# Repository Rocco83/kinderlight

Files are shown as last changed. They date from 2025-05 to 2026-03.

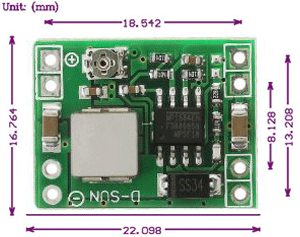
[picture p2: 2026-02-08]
docs/MP1584-Dimensions.png

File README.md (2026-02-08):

# KinderLight RGB

KinderLight RGB is a smart night light based on an ESP32-C6 microcontroller,
capable of automatically adjusting brightness and color based on ambient light using a BH1750 sensor.

Designed to integrate natively with **Home Assistant** via **ESPHome**.

---

## Features

- Automatic ambient light detection with BH1750 sensor.
- RGB LED control via PWM (independent channels for Red, Green, Blue).
- Wi-Fi control and OTA (Over The Air) firmware updates.
- Web server interface for local diagnostics.
- Optional manual serial debug connection via JST-SH 5P or Tag-Connect footprint (future).
- Easy snap-in mount inside a **Vimar Plana** 14041 cover plate.
- Input voltage 7–24V regulated to 5V with buck converter.
- Smooth fade-in and fade-out effects.
- Automatic activation from sunset to sunrise (future).

## Hardware Required

- ESP32-C6 Supermini
- BH1750 light sensor module
- MP1584 DC-DC Stepdown Module
- RGB LED (common anode)
- 3D printed snap-in panel for Vimar 14041
- optionally, the PCB to host the components, otherwise replicate the same BOM

## Software

- ESPHome (latest)
- Home Assistant (latest)
- YAML automations provided.

## Installation

1. Flash the ESP32 using provided `kinderlight.yaml` ESPHome config.
2. Install the snap-in panel inside a Vimar 14041 (or custom box).
3. Wire the RGB LED and the BH1750 sensor
4. Upload automations to Home Assistant.

## Configuration

Lux table:
0.0 - 2.0 lx: Danger Zone (High risk of tripping/hitting furniture).
2.0 - 5.0 lx: Deep Twilight (Silhouettes only; no colors or textures visible).
5.0 - 10.0 lx: Twilight (General shapes visible; fine details are lost).
10.0 - 15.0 lx: Low Orientation (Safe to move; colors begin to be distinguishable).
15.0 - 20.0 lx: Dim Orientation (Comfortable for a nightlight; eye starts to adapt).
20.0 - 30.0 lx: Gloomy Interior (Environment feels "dark" but fully visible).

## Entities Created

- `light.kinderlight_rgb`
- `sensor.ambient_light_lux`

(Optional Voltage monitor if configured.)

## Automation Logic

- Turns on at sunset, off at sunrise.
- During daytime, activates if ambient lux falls below threshold.
- Full color control from Home Assistant dashboard.

## Future Plans

- Support for multiple KinderLights via groups.
- Additional effects (color cycling, breathing mode).

## License

GPL-3.0 License

---

## Project Structure

```plaintext
kinderlight_rgb/
├── README.md
├── LICENSE
├── hardware/
│   └── 3d_models/
│       ├── snapin_14041.stl
│       └── 
├── firmware/
│   ├── kinderlight_rgb.yaml
│   ├── example_automation.yaml
├── bom/
│   ├── bom_front.csv
│   ├── bom_rear.csv
└── tools/
    ├── wiring_diagram.svg
    └── wiring_diagram.png

## Backlog

MP1584 dimensions for kicad has been taken from:

https://components101.com/modules/mini-mp1584-dc-dc-3a-adjustable-buck-module

[docs/MP1584-Dimensions.png]
[docs/MP1584-Pinout.jpg]

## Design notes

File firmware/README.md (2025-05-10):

# KinderLight Firmware

This directory contains the ESPHome configuration for the KinderLight RGB nightlight device.

## 📦 Files

- `kinderlight.yaml`: main ESPHome configuration file for the ESP32 controller.
- `secrets.yaml.example`: example of the secrets file you need to set up for WiFi credentials.

## 🔧 Hardware Configuration

| Component | GPIO  | Notes |
|---|---|---|
| RGB LED - Red PWM | GPIO14 | Controlled via IRLML6344 MOSFET |
| RGB LED - Green PWM | GPIO27 | " |
| RGB LED - Blue PWM  | GPIO26 | " |
| I2C SDA | GPIO21 | Used for BH1750 light sensor |
| I2C SCL | GPIO22 | " |

## 💡 Functionality

- **RGB LED light** with full Home Assistant control.
- **Smooth fading** transitions.
- **BH1750 ambient light sensor** for automatic on/off logic.
- Optional **voltage/battery monitoring** (coming soon).

## 🚀 Flash Instructions

1. Copy `kinderlight.yaml` into your ESPHome config folder.
2. Duplicate `secrets.yaml.example` into your root ESPHome directory as `secrets.yaml`, and set your WiFi credentials.
3. Flash via USB or OTA:
   ```bash
   esphome run kinderlight.yaml

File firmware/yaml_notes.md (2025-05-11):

# KinderLight RGB - YAML Notes

## 📋 General Information

- Firmware is compatible with ESPHome 2024.x versions.
- Ambient light detection using BH1750 sensor over I2C bus.
- RGB LED controlled through independent PWM channels.

## 🛠️ GPIO Pin Assignments

| Function | GPIO |
|---|---|
| PWM Red (LED) | GPIO1 |
| PWM Green (LED) | GPIO2 |
| PWM Blue (LED)  | GPIO3 |
| SDA (I2C Data)  | GPIO8 |
| SCL (I2C Clock) | GPIO9 |

> **Note**:  
> These pin assignments can be modified if needed in the `kinderlight_rgb.yaml` file.

## 🔥 Key Recommendations

- Use **IRLML6344** SOT-23 MOSFETs for production PCB (small, efficient).
- For breadboard testing, you can use **2N7000** MOSFETs (TO-92 package) **without any circuit changes**.
- Recommended PWM frequency: **at least 1000Hz** to avoid visible flicker.

## ⚙️ Electrical Characteristics

- Input voltage range: **10V–12V DC**.
- Buck converter module MP1584EN reduces voltage to stable 5V.
- Ambient light detection threshold: adjustable via YAML, default is **<50 lux** to consider it dark.

## 🛜 Network & OTA

- OTA updates are enabled.
- A fallback Access Point will be created if Wi-Fi is not available during boot.
- Web server interface available at device's IP address (port 80).

---

# 📦 Important Notes

- ESP32-C3 board must be properly connected to the rear PCB via a 5P JST-SH connector.
- Ambient light sensor BH1750 uses I2C address `0x23`.
- RGB light can be fully controlled from Home Assistant dashboards.
- Automation examples are available under `example_automation.yaml`.

---

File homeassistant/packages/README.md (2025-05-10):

         +----------------+
         |    Home Assistant|
         +----------------+
                  |
                  v
         +----------------+
         | sun.sun changes |
         +----------------+
             /        \
            /          \
         sunset       sunrise
           |             |
           v             v
   light.turn_on   light.turn_off
 (with fade 2s)    (with fade 2s)

                  |
                  v
         +----------------+
         | Ambient Light   |
         | Sensor (lux)    |
         +----------------+
             /        \
            /          \
        lux < 30     lux > 50
           |             |
           v             v
   light.turn_on   light.turn_off
 (only daytime)   (only daytime)

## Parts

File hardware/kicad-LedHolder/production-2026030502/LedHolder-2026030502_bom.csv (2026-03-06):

Designator | Footprint | Quantity | Value | LCSC Part #
J1 | JST_PH_S4B-PH-SM4-TB_1x04-1MP_P2.00mm_Horizontal | 1 | JST | C265102
LED1 | LED_D5.0mm-4_RGB_nopackage | 1 | LED_5mm_RABG

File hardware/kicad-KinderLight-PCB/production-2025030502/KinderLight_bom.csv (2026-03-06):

Designator | Footprint | Quantity | Value | LCSC Part #
J1 | PinSocket_1x02_P2.54mm_Vertical | 1 | +5VCC
J10 | JST_PH_B4B-PH-K_1x04_P2.00mm_Vertical | 1 | LED PWM JST | C131334
J11 | JST_PH_B4B-PH-K_1x04_P2.00mm_Vertical | 1 | I2C BH1750 JST | C131334
J2, J6 | PinSocket_1x02_P2.54mm_Vertical | 2 | GND
J3 | PinSocket_1x10_P2.54mm_Vertical | 1 | ESP32C6 Left
J4 | PinSocket_1x10_P2.54mm_Vertical | 1 | ESP32C6 Right
J5 | PinSocket_1x02_P2.54mm_Vertical | 1 | VCC
J7 | JST_XH_B4B-XH-AM_1x04_P2.50mm_Vertical | 1 | I2C BH1750 XH | C161871
J8 | JST_XH_B4B-XH-AM_1x04_P2.50mm_Vertical | 1 | LED PWM | C161871
J9 | TerminalBlock_Phoenix_MKDS-1,5-2-5.08_1x02_P5.08mm_Horizontal | 1 | +12VCC | C22397914
Q1, Q2, Q3 | SOT-23 | 3 | AO3400A | C20917
R1, R2, R3 | 0805 | 3 | 220R | C17557
R4, R5, R6 | 0805 | 3 | 150R | C17471

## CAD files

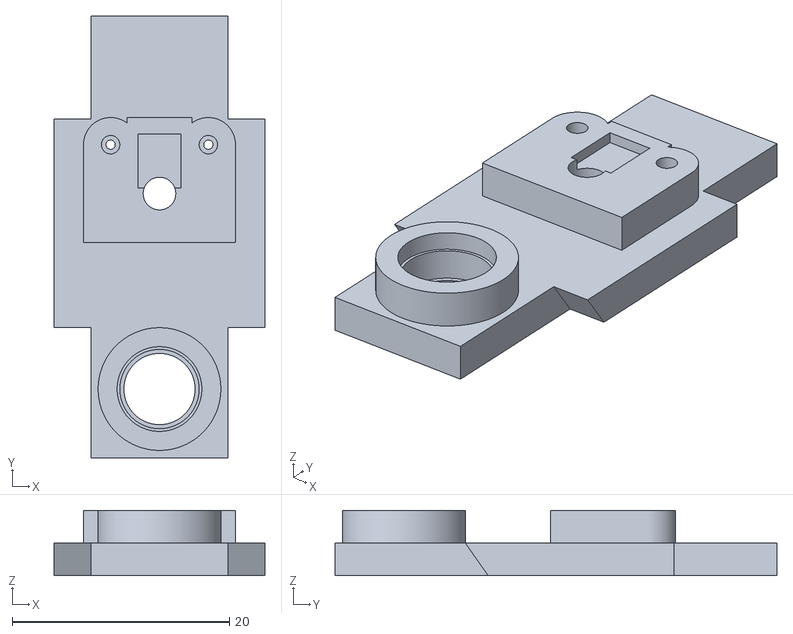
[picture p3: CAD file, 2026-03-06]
hardware/3d_models/snapin_14041_20260130.stl
19.4 x 40.7 x 6.00

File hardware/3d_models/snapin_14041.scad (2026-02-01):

// KinderLight RGB - Snap-in for Vimar 14041 with BH1750 Tower, M2 Towers, and True Snap Hooks
// License: GPL-3.0

//$fn = 20;  // rendering test
$fn = 200; // Smooth curves

// -----------------------------------------------------------------------------
// Main parameters
// -----------------------------------------------------------------------------
// WARNING: PLANA 14041 changed over the time. ensure to have "new" modules

width     = 19.40; // calibro 19,26 (loose) 19,51 (forcing the plastic) - lato non deve premere.
// con 19.26 reali ha ancora agio ma sta bloccato bene
// con 19.27 stampa 19.15
height    = 40.70; // calibro 40,54 (loose) 40,78 (forcing the plastic)
// con 40.58 reali ha ancora agio ma sta bloccato bene
// con 40.58 stampa 40.43
thickness = 3;

abbondanza = 4;

// -----------------------------------------------------------------------------
// Cut of the upper and lower part
// -----------------------------------------------------------------------------
central_module_width = 12.60; // calibro 12.36 in fondo. 12.42 reali ha ancora agio
// con 12.47 reali ha ancora agio ma sta bloccato bene
// con 12.50 stampa 12.39

// 19.3-(3.4*2)=12.5 al contrario: (19.3-central_module_width)/2
slot_depth  = (width - central_module_width) / 2; // "x" (quanto entra verso il centro)
slot_length = 9.5;                                // "y" (lunghezza del taglio lungo il bordo)

// -----------------------------------------------------------------------------
// LED and Sensor positions
// -----------------------------------------------------------------------------
led_pos_y = -14;
led_walls_tickness = 2;
// led diameter: 5mm (si incastra bene)
// led back diameter (che non esce): 5,5mm

hole_diameter_led_pass = 6.55; // Foro dove passa la testa del porta LED
hole_diameter_led_seat = 7.30; // Foro per la base/corpo del porta LED +0.2mm
hole_diameter_led_remove = hole_diameter_led_seat+0.5; // Foro dove passa la testa del porta LED
flange_thickness       = 2;    // Spessore della flangia per NON fare passare il led + 1mm
flange_top_led_remove  = 1.5;
gommino_clearance      = 0;    // 14041 have exactly 2mm spessore

// Sensor hole
sensor_pos_y = 4; // measured, posizione del *sensore* rispetto ad y=0

// -----------------------------------------------------------------------------
// BH1750 main tower
// -----------------------------------------------------------------------------
tower_height           = 3; // 1mm si intravede il foro. 2mm/3mm OK
tower_outer_diameter   = 9; // diametro massimo altrimenti tocca gli altri componenti
tower_inner_diameter   = 7; // which is also sensor diameter

// -----------------------------------------------------------------------------
// Mini-towers M2 screws
// -----------------------------------------------------------------------------
m2_tower_outer_diameter = 5;
m2_tower_inner_diameter = 1.7; // 2.0mm filetto esterno, 1.7mm filetto interno
m2_tower_offset_x       = 4.5;
m2_tower_offset_y       = sensor_pos_y + 4.5; // verificato con calibro


// -----------------------------------------------------------------------------
// MODULES
// -----------------------------------------------------------------------------

// Snap-in base
module snapin_plate() {
    difference() {
        union() {
            // piastra base
            cube([width, height, thickness], center = true);
            // cubo di rinforzo
            translate([0, sensor_pos_y, thickness / 2])
                cube([14, tower_outer_diameter, tower_height * 2], center = true);
            // cilindro per non far fare troppa luminosita' al led
            translate([0, led_pos_y, thickness / 2])
                // il cilindro è alto come la torre per sicurezza
                cylinder(h = tower_height, d = hole_diameter_led_seat+(led_walls_tickness*2));
        }

        // --- SISTEMA FORO LED CON FLANGIA ---
        // 1. Foro passante centrale
        translate([0, led_pos_y, 0])
            cylinder(h = thickness + abbondanza, d = hole_diameter_led_pass, center = true);

        // 2. Scasso per il corpo del LED
        // la flangia deve avere 2 diametri per permettere l'inserimento del led
        translate([0, led_pos_y, -thickness / 2 + flange_thickness])
            cylinder(h = thickness + abbondanza, d = hole_diameter_led_seat);
        // la parte in alto deve avere un minimo di scasso per permettere l'inserimento e l'estrazione del led
        translate([0, led_pos_y, (thickness / 2) + tower_height - flange_top_led_remove])
            cylinder(h = thickness + abbondanza, d = hole_diameter_led_remove);


        // Sensor hole
        scasso_cavi_sensore();

        // Right+left hole for the screw
        buco_per_viti();

        // --- PARAMETRI EXTRA PER GLI SCASSI ---
        slot_extension_length = 2.5; // Lunghezza erosione rettangolare
        cutout_angle          = 35;  // Angolo dello scasso

        // Four vertical notches on long sides
        for (side = [-1, 1]) { // sinistra/destra
            x_pos = side * (width / 2 - slot_depth / 2);

            for (edge = [-1, 1]) { // sopra/sotto
                // Posizionamento Y base
                y_pos = edge * (height / 2 - slot_length / 2);

                // 1. Scasso originale standard
                translate([x_pos, y_pos, 0])
                    cube([slot_depth, slot_length, thickness + abbondanza], center = true);

                // --- MODIFICA SU RICHIESTA (edge -1) ---
                if (edge == -1) {
                    
                    // Direzione verso il centro (per Y neg è 1)
                    dir_to_center = 1;

                    // Bordo interno dello scasso originale
                    y_inner_edge = y_pos + dir_to_center * (slot_length / 2);

                    // 1) ERODI LUNGHEZZA PARAMETRICA
                    translate([x_pos, y_inner_edge + dir_to_center * (slot_extension_length / 2), 0])
                        cube([slot_depth, slot_extension_length, thickness + abbondanza], center = true);

                    // 2) SCAVO TRIANGOLARE PARAMETRICO
                    y_prism_start = y_inner_edge + dir_to_center * slot_extension_length;

                    // Calcolo dello sbalzo (cateto orizzontale) basato sull'angolo
                    offset_y = thickness * tan(cutout_angle);

                    translate([x_pos, y_prism_start, 0])
                        rotate([90, 0, 90])
                        linear_extrude(height = slot_depth, center = true)
                        polygon(points = [
                            // Largo sotto, stretto sopra
                            [0, thickness / 2], // In ALTO: Punta stretta
                            [0, -thickness / 2], // In BASSO: Inizio base larga
                            // In BASSO: Fine base larga calcolata trigonometricamente
                            [dir_to_center * offset_y, -thickness / 2]
                        ]);
                }
            }
        }
    }
}

module scasso_cavi_sensore() {
    // Posizionamento sulla cima della torre tra M2 e Sensore
    translate([0, m2_tower_offset_y, (thickness / 2 + tower_height)])
        translate([-2, -4, -0.9])
        cube([4, 5, 0.91]);

    vimar_tickness          = 1.9;
    base_cone               = 2;
    top_cone                = 2;
    sensor_minimum_diameter = 3;

    z0cone                     = -thickness / 2 - vimar_tickness;
    cone_groove_width          = 2;   // la parte del gommino che deve passare
    cone_groove_inner_diameter = 7.5; // gommino 7.00, tieni del margine 
    cone_groove_outer_diameter = 9;   // parte esterna gommino
    cone_top_width             = 3.5;   // altezza dopo groove fino a top

    // #1 2mm dritto dalla base (base_cone)
    translate([0, sensor_pos_y, z0cone])
        cylinder(h = base_cone, d = tower_inner_diameter);

    // #2 cono
    translate([0, sensor_pos_y, z0cone + base_cone])
        cylinder(h = thickness + tower_height - top_cone,
            d1 = tower_inner_diameter,
            d2 = 3); // sensor longest side: 2.5mm. 3 for clearance

    // #3 2mm dritto (top_cone)
    translate([0, sensor_pos_y, z0cone + base_cone + thickness + tower_height - top_cone])
        cylinder(h = top_cone, d = sensor_minimum_diameter);


    // OPZIONALE, spazio per il gommino
    spazio_per_gommino = 1;
    if (spazio_per_gommino == 1) {
        // dalla base, altezza della base, fai scasso con diametro esterno
        translate([0, sensor_pos_y, z0cone])
            cylinder(h = cone_groove_width, d = cone_groove_inner_diameter);

        // spazio per incastro parte alta gommino        
        translate([0, sensor_pos_y, z0cone + cone_groove_width])
            cylinder(h = cone_top_width, d1 = cone_groove_outer_diameter, d2 = cone_groove_inner_diameter);
    }
}
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

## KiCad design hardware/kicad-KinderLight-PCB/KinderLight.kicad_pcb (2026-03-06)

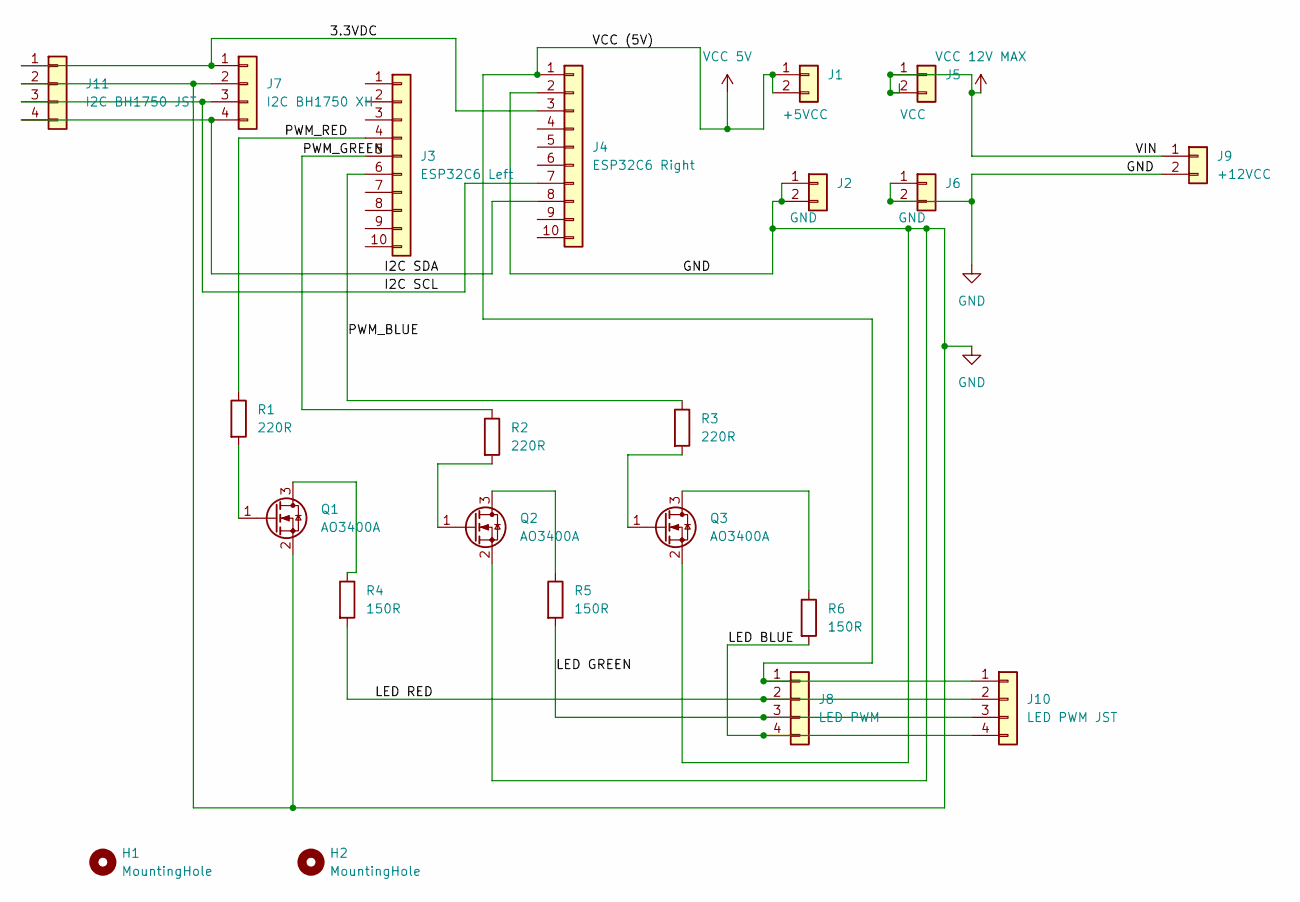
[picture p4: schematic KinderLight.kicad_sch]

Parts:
H1, H2: MountingHole; MountingHole_3.2mm_M3
J1: +5VCC; PinSocket_1x02_P2.54mm_Vertical
J2, J6: GND; PinSocket_1x02_P2.54mm_Vertical
J3: ESP32C6 Left; PinSocket_1x10_P2.54mm_Vertical
J4: ESP32C6 Right; PinSocket_1x10_P2.54mm_Vertical
J5: VCC; PinSocket_1x02_P2.54mm_Vertical
J7: I2C BH1750 XH; JST_XH_B4B-XH-AM_1x04_P2.50mm_Vertical; LCSC C161871
J8: LED PWM; JST_XH_B4B-XH-AM_1x04_P2.50mm_Vertical; LCSC C161871
J9: +12VCC; TerminalBlock_Phoenix_MKDS-1,5-2-5.08_1x02_P5.08mm_Horizont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; LCSC C22397914
J10: LED PWM JST; JST_PH_B4B-PH-K_1x04_P2.00mm_Vertical; LCSC C131334
J11: I2C BH1750 JST; JST_PH_B4B-PH-K_1x04_P2.00mm_Vertical; LCSC C131334
Q1, Q2, Q3: AO3400A; SOT-23; LCSC C20917
R1, R2, R3: 220R; R_0805_2012Metric; LCSC C17557
R4, R5, R6: 150R; R_0805_2012Metric; LCSC C17471

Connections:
/3.3VDC: J4.3, J7.1, J11.1
/I2C SCL: J4.7, J7.3, J11.3
/I2C SDA: J4.8, J7.4, J11.4
/LED BLUE: J8.4, J10.4, R6.2
/LED GREEN: J8.3, J10.3, R5.2
/LED RED: J8.2, J10.2, R4.2
/PWM_BLUE: J3.6, R3.1
/PWM_GREEN: J3.5, R2.1
/PWM_RED: J3.4, R1.1
GND: J2.1, J2.2, J4.2, J6.1, J6.2, J7.2, J9.2, J11.2, Q1.2 (S), Q2.2 (S), Q3.2 (S)
unnamed: Q1.3 (D), R4.1
unnamed: Q1.1 (G), R1.2
unnamed: Q2.3 (D), R5.1
unnamed: Q2.1 (G), R2.2
unnamed: Q3.3 (D), R6.1
unnamed: Q3.1 (G), R3.2
VCC 5V: J1.1, J1.2, J4.1, J8.1, J10.1
VCC 12V MAX: J5.1, J5.2, J9.1

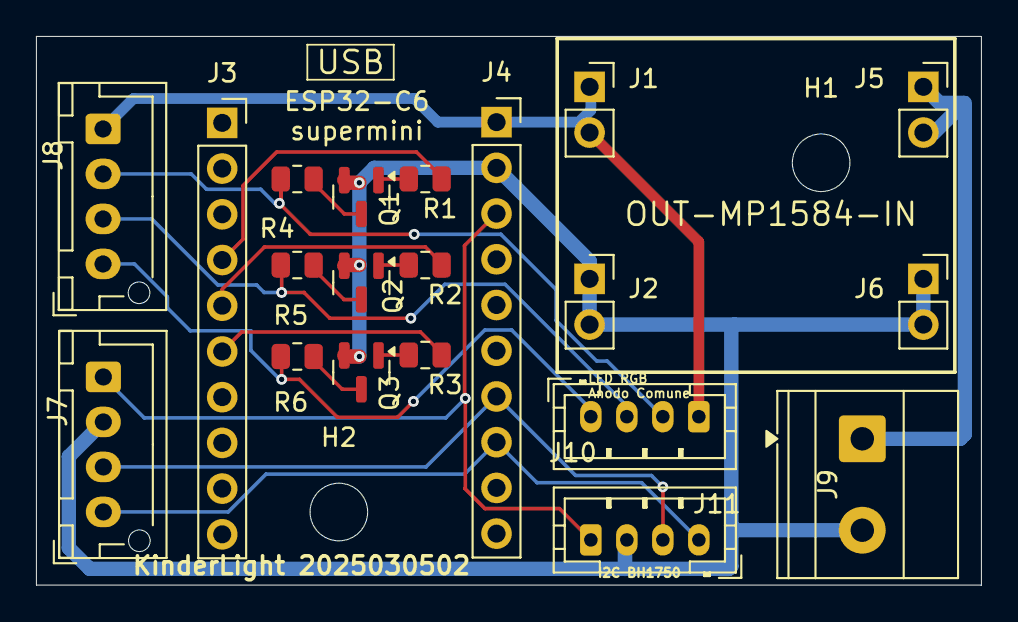
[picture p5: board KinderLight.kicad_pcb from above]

Board: 2 copper layers, 52.5 x 30.5 mm, 22 parts (0 on the bottom side), 18 nets.

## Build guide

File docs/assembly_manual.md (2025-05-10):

# KinderLight RGB - Assembly Manual

This guide will help you assemble both the Front PCB and the Rear PCB of the KinderLight RGB project.

---

## 📋 General Requirements

- Soldering iron with fine tip
- Solder wire (preferably leaded 60/40 for easier work)
- Flux (recommended for SMD parts)
- Tweezers (for SMD parts handling)
- Small wire cutters
- JST-SH 1.0mm crimping tool (optional but recommended)

---

## 🛠️ Front PCB Assembly Steps

1. **Place and solder resistors (Through-Hole):**
   - R1: 150Ω (Red LED current limit)
   - R2: 100Ω (Green LED current limit)
   - R3: 100Ω (Blue LED current limit)
   - R4, R5, R6: 10kΩ (Gate pull-down resistors)

2. **Place and solder SMD MOSFETs:**
   - Q1, Q2, Q3: IRLML6344 (SOT-23 package)
   - *(Use flux and tweezers, or reflow manually.)*

3. **Place and solder the RGB LED (Through-Hole):**
   - LED1: RGB common cathode, 5mm.

4. **Place and solder BH1750 Light Sensor:**
   - U1: BH1750 module (direct or via pin header).

5. **Place and solder JST-SH connectors:**
   - J1: 7P (Main RGB + I2C)
   - J2: 5P (Serial debug)

6. **(Optional)** Solder Tag-Connect TC2030 footprint pads if needed.

---

## 🛠️ Rear PCB Assembly Steps

1. **Place and solder JST-SH 5P connectors:**
   - J3: Input from Front PCB (serial + power).
   - J4: Output to ESP32 DevKit Mini (serial + reset).

2. **Place and solder Buck converter:**
   - DC1: MP1584EN module (12V → 5V).
   - Secure it mechanically if needed with glue or brackets.

3. **Mount ESP32-C3 Mini DevKit:**
   - Connect via header pins or female socket.

4. **(Optional)** Place and solder a battery connector:
   - BAT_CONN: 2-pin connector for backup battery.

5. **(Optional)** Solder Tag-Connect TC2030 footprint pads for programming/debugging.

---

## 🔥 Important Assembly Notes

- Always double-check MOSFET orientation (Drain, Source, Gate).
- Verify LED polarity: common cathode must go to GND.
- Use multimeter continuity mode to check shorts before applying power.
- Verify 5V stable output from Buck Converter before connecting ESP32.
- Use JST-SH cables correctly: color-code the wires if possible.

---

## 🎯 Initial Power-Up Checklist

- Check 12V input arriving to Buck Converter.
- Check 5V stable at ESP32 VCC.
- Confirm ESP32 boot by serial console or WebServer.
- Verify light sensor BH1750 detection (via ESPHome logs).
- Test LED RGB color control via Home Assistant.

---

# 🚀 Congratulations!

You have successfully assembled your KinderLight RGB unit!  
Enjoy your smart and modular nightlight system.

---

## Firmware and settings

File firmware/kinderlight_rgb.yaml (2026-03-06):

esphome:
  # this is the hostname, the mac_suffix will differentiate the device
  name: kinderlight-rgb
  friendly_name: KinderLight-RGB
  name_add_mac_suffix: true
  on_boot:
    priority: 600 # Run after sensors are initialized
    then:
      - lambda: |-
          // Restore the curve from Flash string to RAM vector
          std::string s = id(calib_storage);
          std::string delimiter = ",";
          size_t pos = 0;
          std::string token;
          int i = 0;

          ESP_LOGI("storage", "Restoring calibration curve: %s", s.c_str());

          // Parse CSV string
          while ((pos = s.find(delimiter)) != std::string::npos && i < 11) {
              token = s.substr(0, pos);
              id(calib_curve)[i] = strtof(token.c_str(), NULL);
              s.erase(0, pos + delimiter.length());
              i++;
          }
          // Handle the last value
          if (i < 11) {
             id(calib_curve)[i] = strtof(s.c_str(), NULL);
          }

esp32:
  board: esp32-c6-devkitm-1
  framework:
    type: esp-idf

# Enable logging via UART
logger:

# default HA integration, OTA updater and backup http web portal
api:
  # TODO increase the security
  # password: !secret device_password
  #encryption:
  #  key: "YOUR_ENCRYPTION_KEY"
  # 5m default delay. if no home assistant, then force reboot
  reboot_timeout: 0s

ota:
  - platform: esphome
  # TODO increase the security
  # password: !secret device_password
  # change to https://esphome.io/components/ota/http_request ?

wifi:
  # Read the wifi/pass from secrets.yaml and support 2 SSID
  networks:
  - ssid: !secret wifi_1_ssid
    password: !secret wifi_1_password
  - ssid: !secret wifi_2_ssid
    password: !secret wifi_2_password
  #output_power: 17dB          # Default TX power, increased dynamically if needed
  post_connect_roaming: true  # Scan for better AP after connection
  #reboot_timeout: 90s         # Reboot if unable to connect within 90 seconds

# Web server for local diagnostics
web_server:
  port: 80
  version: 3

# I2C Bus for BH1750 sensor
i2c:
  sda: GPIO14 # 8th pin right
  scl: GPIO15 # 7th pin right
  #scan: true #
  id: i2c_bus_a

globals:
  # Working vector (RAM) - stores the offsets: 0%, 10%, ... 100%
  # Initialized with your measured deltas (Measured - 0.1 lux baseline)
  - id: calib_curve
    type: std::vector<float>
    initial_value: '{0.0, 0.0, 0.4, 1.0, 2.4, 4.7, 7.6, 11.8, 17.3, 23.9, 31.8}'

  # Persistent storage (Flash) - saves curve as CSV string
  - id: calib_storage
    type: std::string
    restore_value: true
    initial_value: '"0.0,0.0,0.4,1.0,2.4,4.7,7.6,11.8,17.3,23.9,31.8"'

  # Helper iterator for the calibration loop
  - id: calib_iterator
    type: int
    initial_value: '0'

script:
  - id: run_dynamic_calibration
    mode: restart

    # ADDED: Define all incoming parameters
    parameters:
      init_override: bool
      init_on: bool
      init_bri: float
      init_r: float
      init_g: float
      init_b: float

    then:
      - logger.log: "Starting Dynamic Calibration (11 steps)..."

      # Reset iterator and turn off light
      - globals.set:
          id: calib_iterator
          value: '0'
      # ensure that override is ON
      - switch.turn_on: manual_override
      # turn off the light
      - light.turn_off: kinderlight_rgb_light
      # wait before starting to reduce the light
      - delay: 5s

      # Measure Baseline (0%)
      - lambda: |-
          // Store baseline (ambient light)
          // We temporarily store the raw value in index 0
          float val = id(ambient_light).state;
          id(calib_curve)[0] = val;
          ESP_LOGI("calib", "Baseline: %.1f lx", val);

      # Loop steps 1 to 10 (10% - 100%)
      - repeat:
          count: 10
          then:
            - lambda: 'id(calib_iterator) += 1;'

            # Set brightness
            - light.turn_on:
                id: kinderlight_rgb_light
                brightness: !lambda 'return id(calib_iterator) / 10.0;'
                red: 100%
                green: 100%
                blue: 100%
                transition_length: 1s

            - delay: 5s # Wait for sensor

            # Measure and calculate Delta
            - lambda: |-
                int i = id(calib_iterator);
                float current_lux = id(ambient_light).state;
                float baseline = id(calib_curve)[0]; // Retrieve raw baseline

                // Calculate how much light the lamp is adding
                float delta = current_lux - baseline;
                if (delta < 0) delta = 0;

                if (i < 11) {
                  id(calib_curve)[i] = delta;
                  ESP_LOGI("calib", "Step %d: Delta %.1f", i, delta);
                }

      # Finish: Reset index 0 to 0.0 (baseline offset is always 0)
      - lambda: 'id(calib_curve)[0] = 0.0;'

      # Turn off light
      - light.turn_off: kinderlight_rgb_light
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

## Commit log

2025-05-10 review needed for firmware
    [kinderlight_rear2.sch]
2025-05-11 fixed firmware
    merged & removed v2 and v3 code
    modified gitignore to skip secrets.yaml
    edited the pin in use
    merged & removed sidecars files
    [kinderlight_rgb.yaml]
2025-12-27 Prod 1.0
    Removed day change of light - commented
    Added button for reset of memory - when the sliders are missing, in example
    [kinderlight_rgb.yaml]
2025-12-27 v2 - still to be confirmed
    [snapin_14041.scad]
2025-12-28 first test snapin
    [snapin_14041.scad, snapin_14041.stl]
2025-12-28 removed old hardware, added kicad
    [KinderLight-B_Cu.gbr, KinderLight-B_Mask.gbr, KinderLight-B_Silkscreen.gbr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]
2026-01-09 test version for the scad file
    [snapin_14041.scad, snapin_14041.stl]
2026-01-11 rev3 scad file
    [snapin_14041.scad]
2026-01-11 removed the snaps (unused)
    [snapin_14041.scad]
2026-01-11 fixed the width to be parametric
    This is now based on the internal width, easier to be calculated
    [snapin_14041.scad]
2026-01-11 added test stl
    [snapin_14041.stl]
2026-01-20 removed unused openscad code, reverted to fn=200
    [snapin_14041.scad]
2026-01-24 fix & print
    [snapin_14041.scad]
2026-01-24 removed unused file
    [snapin_14041.scad]
2026-01-24 Version 20260124v2
    version v1 (no v) differ from groove height
    [snapin_14041.scad]
2026-02-01 3d version 20260131
    - fixed dimensions for adapting the print
    - added a lager led holder seat on the top
    [snapin_14041.scad]
2026-02-02 Beta 1.0
    Removed unused files
    in the esphome file
    - enforced the esp-idf framework
    - added a multiplier in case of the reading of the sensor is off target
    - moved to text instead of sliders the single colors of the RGB
    - added a default value of 100 for the single textbox
    - added the offset for darkness with calculations
    - improved the Darkness Threshold slider
    - added the KinderLight Hostname field - not working as intended for now
    [kinderlight_front.sch, kinderlight_rear.sch, kinderlight_rear2.sch]
2026-02-02 Beta 2.0
    - Improved the automatic calculation
    - removed obsolete code
    - moved some buttons around config and diagnostic
2026-02-02 Sensor multiplier and calibration fix
    The sensor multiplier is not fixed to 1 anymore
    It has a default of x2 (based on empiric test on Plana 14041 as by 3d model)
    Also, the values are visible in diagnostic.
    In the calibration the time has been moved from 3s to 5s
    In 3 seconds the light sensor is still assessing the proper value.
    [kinderlight_rgb.yaml]
2026-02-02 Refined the calibration, fixed the initial bright
    The calibration was not turning off the manual override - to avoid flapping
    The initial brightness of the RGB led should be 50%
    [kinderlight_rgb.yaml]
2026-02-08 Added version 20260207 of the PCB
    [KinderLight-B_Cu.gbl, KinderLight-B_Mask.gbs, KinderLight-B_Silkscreen.gbo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]
2026-02-08 Added reboot button
2026-03-06 WiFi improvements
    WiFi was stable but not working. This has been solved at AP side.
    Anyhow, some improgements has been done in the code.
    - added a debug on the WiFi signal in the log
    - implemented post_connect_roaming
    - moved the limit from -80dB to -90dB
    [kinderlight_rgb.yaml]
2026-03-06 Added production version of the snapin
    This is the version printed in the main batch
    [snapin_14041_20260130.stl]
2026-03-06 removal of old gerber and production files
    [KinderLight-B_Cu.gbr, KinderLight-B_Mask.gbr, KinderLight-B_Silkscreen.gbr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]
2026-03-06 removal of the old stl file - never produced
    [snapin_14041.stl]
2026-03-06 removed another gerber file
    [KinderLight-B_Cu.gbl, KinderLight-B_Mask.gbs, KinderLight-B_Silkscreen.gbo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]
2026-03-06 Added the production file for the PCB sent
    [KinderLight-B_Cu.gbl, KinderLight-B_Mask.gbs, KinderLight-B_Silkscreen.gbo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]
2026-03-06 Added the kicad source file of the production batch
    [KinderLight.kicad_pcb, KinderLight.kicad_sch]
2026-03-06 Added ledholder breakout, renamed kicad main pcb
    [KinderLight-B_Cu.gbl, KinderLight-B_Mask.gbs, KinderLight-B_Silkscreen.gbo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]
2026-03-06 First beta for the PCB box - NOT correct
2026-04-04 Added the last calibration time and fixed defaults
    The new last calibration time has been added
    The default values has been changed to reflect
    - the default lux threshort
    - the default calibration map
